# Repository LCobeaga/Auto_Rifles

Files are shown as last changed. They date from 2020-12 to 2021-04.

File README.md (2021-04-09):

Auto Rifles
=====

pretty shot

###### This is a Re-draw of Shadow Price with significant structural and aesthetic improvements that I made over the summer of 2020. It is now to-scale compared to in Destiny and much easier to edit. I plan to make all the other variants of stocks, barrels, and frames seen in the game. Internally, it is still BLDC flywheels and solenoid pusher, but now uses a 16 bit display ammo counter, and includes select fire. It also uses hardware to hold the blaster toghether, unlike the original which was mostly glued together. As a result, most visual components are separate parts, so even without paint the blaster should look very nice, and allows for color swaps if multiple aesthetic components are printed. 

### HARDWARE
#### MECHANICAL
- Six 5mm x 400mm carbon fiber rods
- Five M3 x 8mm heatset inserts
- Three M2 x 4mm heatset inserts
- Five 10mm Nerf style screw
- Four M3 x 12 screws (I used hex socket)
- One M3 x 8 screw
- Four pen springs (one for trigger, two for mag release, and one for priming rod play feature)
- About 1 inch (30mm) of half inch or 14mm PVC pipe (to straighten dart as it leaves the flywheels)
- Electrical or Painters tape (to center and hold pipe at base of barrel)
- ~Four 1kg spools of filament (more if using multiple colors)
#### ELECTRICAL
- One 35mm solenoid (designed for FTW hyperdrive solenoid so a regular one might not fit) https://flywheeltheworld.com/shop/ftw-hyperdrive-solenoid/
- Two 2300KV brushless motors (currently supports 2204 and 1806)
- Two ESCs matching motor amperage draw
- One XT-60 (or preffered) male battery connector
- Two 6mm surface mount (or breadboard compatible) pushbutton switch
- Two D2F-01L3 momentary limit switches (I used the rounded lever)
- One MOSFET or pre-built mosfet board 
- One 10kΩ resistor (only if using raw MOSFET)
- One IN5408 diode (only if using raw MOSFET)
- One 10kΩ potentiometer
- One 32 x 128 I2C OLED display (https://www.dfrobot.com/product-2019.html this is the only one that I know works, but any with the same shape would work too)
- One Arduino Pro Mini 
- High Amperage wires for battery to MOSFET and ESCs
- Small wires for Arduino Connections
- OPTIONAL: JST or other connector type for removeable connections (good for troubleshooting)
- OPTIONAL: Solderable breadboard/raw PCB for wire management

### WIRING DIAGRAM

Auto Rifle

### ASSEMBLY 

1. Glue together the two handle halves (use the lower and knuckle guard bottom to align)



2. Glue handle into the lower



3. Glue details into lower





4. Glue lower covers to lower (make sure to have them align with the cut out for the solenoid



5. Glue lower filler into lower (make sure it is pushed all the way in)


6. Glue together the two knuckle guard pieces



7. Slot mag tooth with spring into lower, slot mag release into the handle, and place the lever into the lower from below



8. Snap the handle cover into place by rotating it in about the trigger guard



9. Slot top of knuckle guard into lower, around the lever and mag release, then slot the tab into the recepticle in the handle and use a nerf screw to lock it in





10. Press magwell covers into slots on either side (DO NOT GLUE, will need to remove later to access wires)



11. Slot in prime pin and prime, place spring behind prime so it will bounce back forward after getting pulled back (can also add some lubricant to smooth movement)



12. Glue detail parts into upper



13. Glue top picatiny into ammo counter (make sure bottom surface flush, the assembly slots into the upper)



14. Glue details into archway



15. Glue archway, top cover, and tail together (assembly called the frame)



16. Cut a 400mm carbon fiber rod in half, and glue into top and bottom of stock filler. Align by first putting rods into upper and lower, then pushing stock filler into them. (all other parts can be optionally glued in, but I suggest against it)



The blue spirals are the M3 heat set inserts, can be added now or later, it does not matter

17. Glue the battery tray strap into the battery tray



#### NO MORE GLUING FROM THIS POINT ON

18. Slot details into stock, and slide stock into dovetails. Place buttstock on back of stock filler. Screw one side of the stock panels into the standoff, then run standoff through the stock filler and screw on other side (they get centered by the upper so dont worry about lateral spacing)



19. Prepare locking lug by inserting the two M3 heat set inserts into the holes



12. At this point you can begin wiring up the blaster, all electronics are housed in the upper other than the trigger switch. Below are photos of switch placement. Wire all switches as normally open, and the mag sensor switch will need the tabs cut down a little if they are too long (the mag sensor can also be flipped upside down if it registers more consistently)





Parts removed for visual clarity



Place a switch on both sides



Make sure not to glue in the OLED or it will make accessing the potentiometer harder



Route ESC and battery cables through this slot (it is ok for them to spill over into the open space, it is well above the magazine and gets covered up)

Add the final M3 Heat set insert into the hole marked by a red spiral

21. Once all the wiring is done, Screw together the flywheel cage assembly, and add in the three M2 heat set inserts to the cage (be careful to not melt through the top of the cage or it will interfere with the flywheels)



22. Slot trigger and trigger axle into the hole in the trigger well, and add the final pen spring in the hole behind it (rotate them in then push up until it snaps in place)



23. Slot stock assembly into back of upper and lower, and screw in the top and bottom



24. Place the barrel filler over the lower filler and slot in another carbon fiber rod (DO NOT GLUE) making sure the rod is flush against the inside of the lower and the front of the barrel (you will have to cut the rod). Also dont forget to place the lock in the front slot of the barrel filler and the barrel rail in the slot on top



25. Place the center filler over the flywheel cage and lock it by slotting the locking lug from behind and another carbon fiber rod from the front. This rod should stick out a little at the front because it sticks into the barrel faceplate, so make sure to check its length and have it flush against the inner wall of the upper. Also screw it down with the longer M3 screws



26. Wrap tape around the small length of PVC and push it down the barrel so it is flush with the front of the flywheel cage

barrel insert

27. Once all the electronics are inside, snap the ammo counter cover into the upper by squeezing the sides, placing it into the cavity, teetering it back and snapping the sides out (make sure they snap past these tabs)


28. Slot ammo counter and picatiny assembly over the electronics and OLED (red arrow), then rotate the oled into the slot on the ammo counter and use the shorter M3 screw to lock it down (blue arrow)



29. Snap the frame over the upper, it will lock in at the front, back, and slot over the cut out in the ammo counter



30. Snap in the top cowl and add the last Nerf screw to hold it down



31. Slot on the barrel clip, it will snap in place once in position



32. Stack up the three parts of the side panels and push a carbon fiber rod almost all the way through them, but dont go through the rectangular opening at the end



33. Push the panel assembly through the barrel clip from the back, and once far enough the opening in the panel will lock over the arc pop-out in the upper and lower



34. Slot on the barrel. It will mesh with the top and both panel carbon fiber rods, and sit flush against the barrel filler front surface and lower rod, so they all need to be at the correct length for this step (tip: if you have problems aligning the rods, push them into the barrel FIRST so you just press the assembly into position, slotting all the rods at the same time)



barrel tips

35. Screw on the muzzle, snap in the battery tray and lock it with the second barrel and you are done!



## CODE

You will need four external libraries to run the code for this blaster. 

They are:
- JC button library https://github.com/JChristensen/JC_Button
  - built in pullup resistor commands, inversion, and debouncing
- Adafruit GFX and SSD1306 (downloadable thru arduino library manager)
  - controls OLED display with easy to understand commands
- Ammo counter (self written library, available in the code directory)
  - ammo counter code written by Monty Choy converted to a library
  
Current issues to work out:
- more descriptive interface with user

## CUSTOM PANELS

If you would like custom panels like the ones on my personal blaster (seen at the top of the read me) a step file is available in the STEP directory. 

The provided STEP includes the two panels as single, large parts and a new barrel clip that does not extend into the central cutout. 
As long as you dont fill in the hole for the rod, the slot in the back, or the cutouts that mesh with the barrel in the front, you can add anything you want to the panels. 
If your printer is not large enough for a full panel (like mine) you can make a design along where you plan to cut the panel, like the eagle head on my personal blaster.
Have fun with it and personalize your blaster to your tastes!

## Fusion File Downloads

They are massive, like 60MB, so if you want them just shoot me an email.

<br />This work is licensed under a <a rel="license" href="http://creativecommons.org/licenses/by-nc-sa/3.0/">Creative Commons Attribution-NonCommercial-ShareAlike 3.0 Unported License</a>.

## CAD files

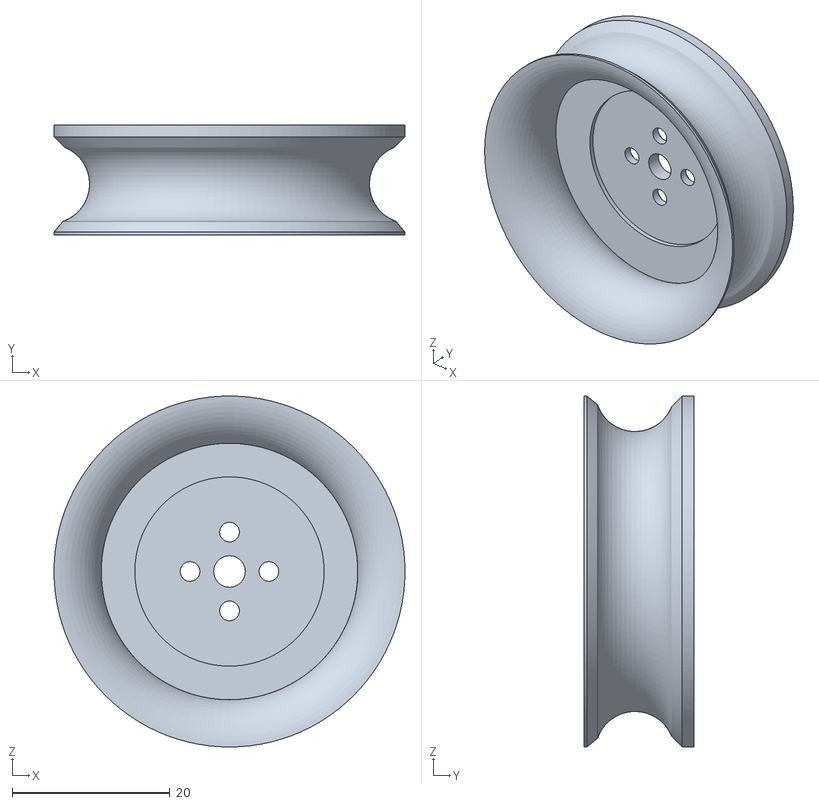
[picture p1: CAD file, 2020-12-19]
parts/cages and wheels/flywheel 2205.stl
44.5 x 14.0 x 44.5

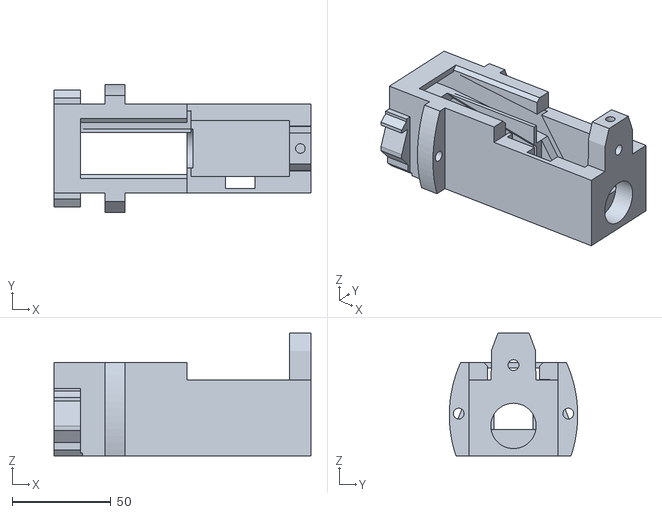
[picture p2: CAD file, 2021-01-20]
parts/Parts_for_smaller_printers/front upper.stl
130.2 x 65.1 x 62.2

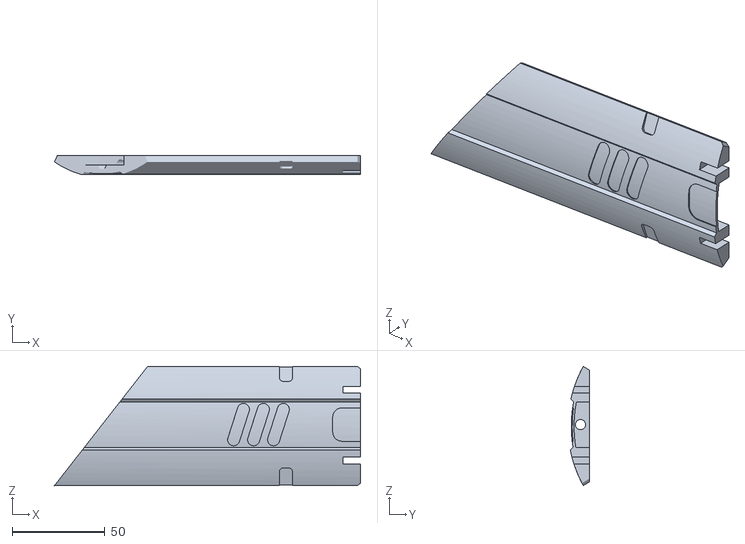
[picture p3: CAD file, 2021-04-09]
parts/Shadow_Price_panels/Front right.stl
165.0 x 10.4 x 64.2

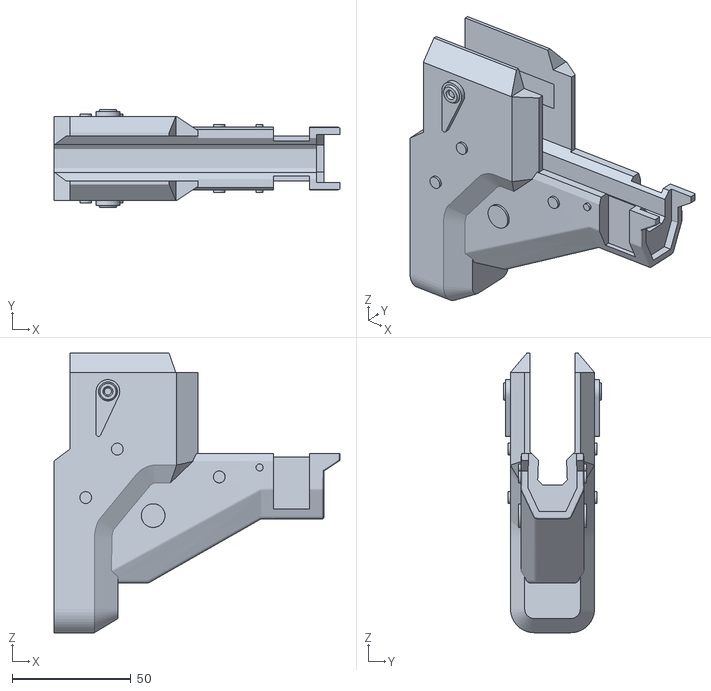
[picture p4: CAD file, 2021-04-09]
parts/stock.stl
120.6 x 41.5 x 117.9

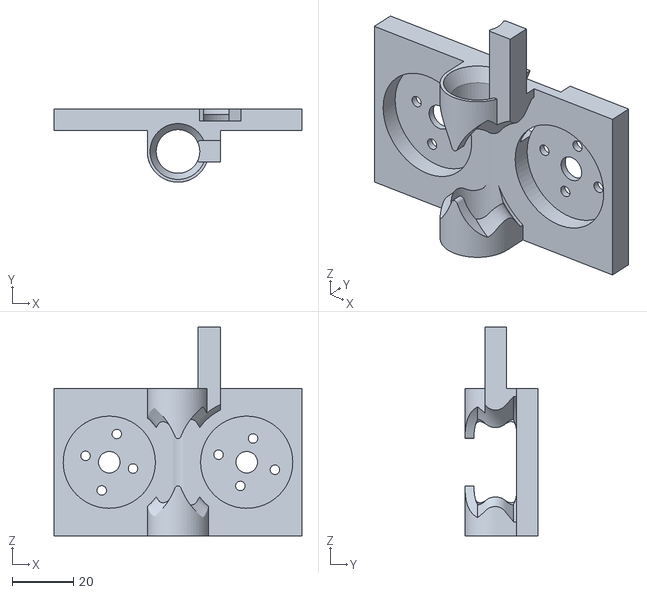
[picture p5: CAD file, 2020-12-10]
parts/cages and wheels/flywheel cage 2205.stl
80.7 x 23.9 x 68.0

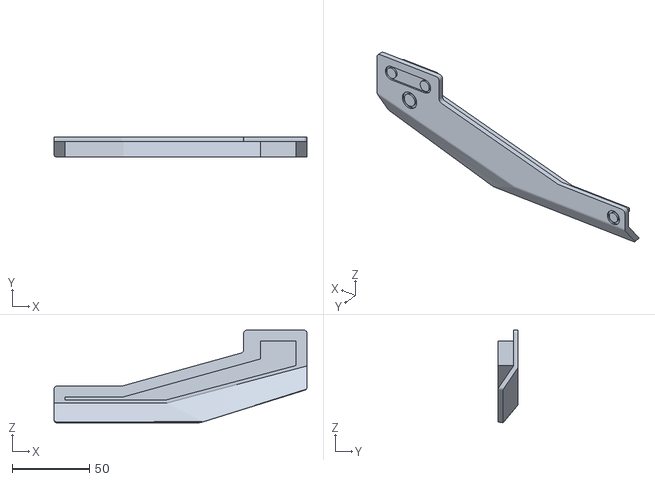
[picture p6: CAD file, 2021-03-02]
parts/left magwell cover.stl
163.8 x 13.1 x 60.0

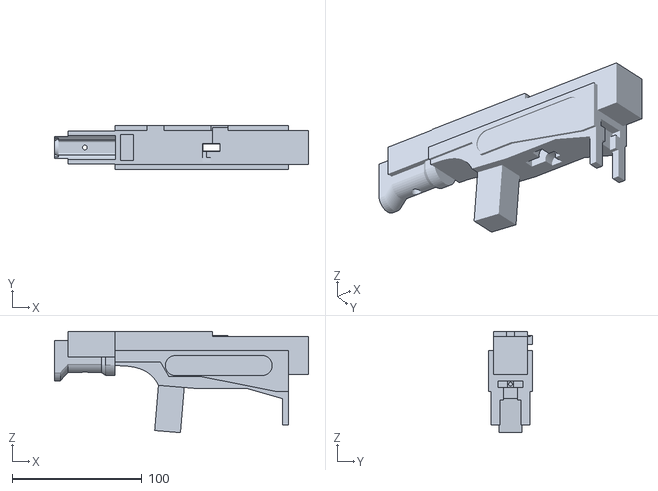
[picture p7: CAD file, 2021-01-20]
parts/Parts_for_smaller_printers/back lower.stl
196.0 x 34.0 x 78.2

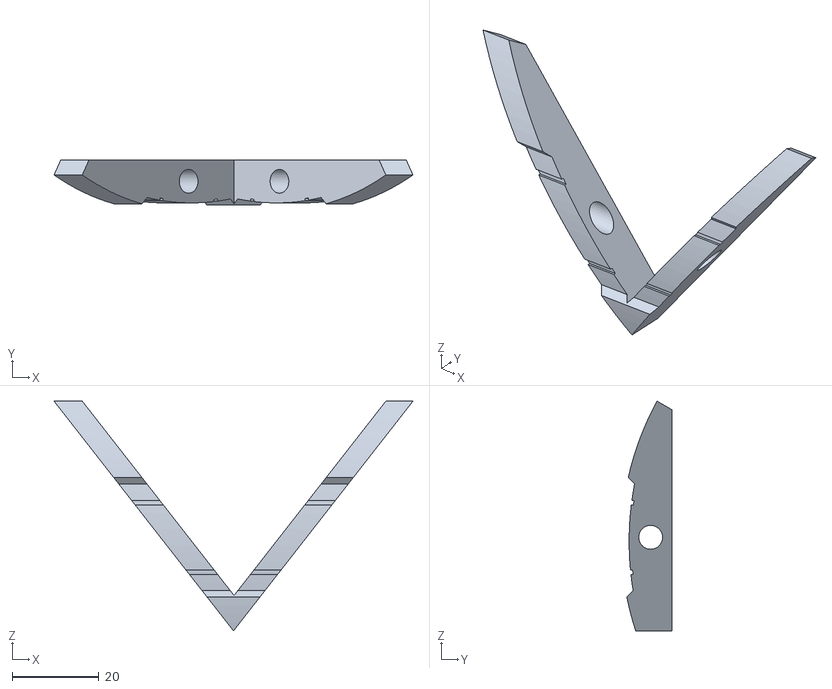
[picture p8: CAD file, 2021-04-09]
parts/Shadow_Price_panels/V gap right.stl
82.7 x 10.4 x 52.9

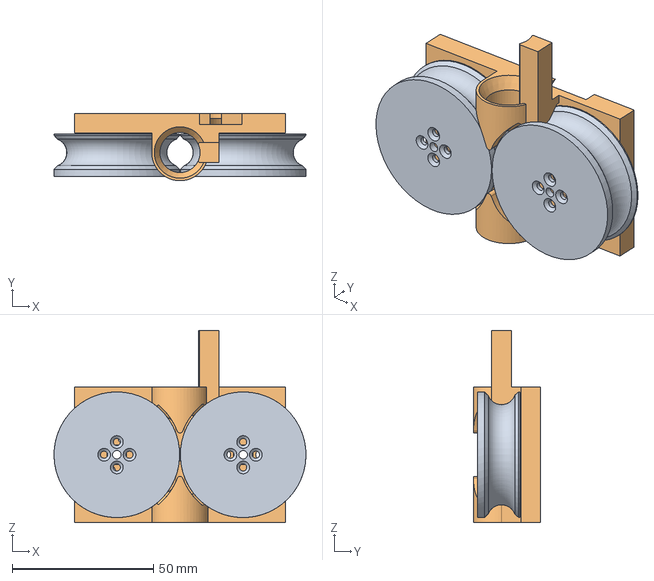
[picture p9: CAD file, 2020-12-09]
parts/cages and wheels/BLDC high crush cage flat 1806 .step
89.2 x 23.9 x 68.0 mm
flywheel_lathed_hi_crush 1806 x 2

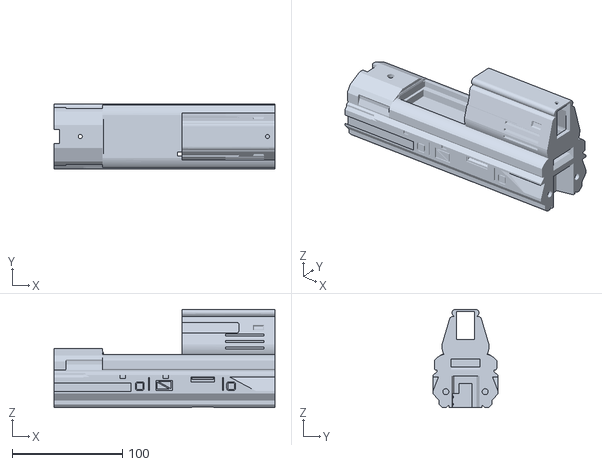
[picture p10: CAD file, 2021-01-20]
parts/Parts_for_smaller_printers/back upper.stl
200.9 x 59.1 x 89.4

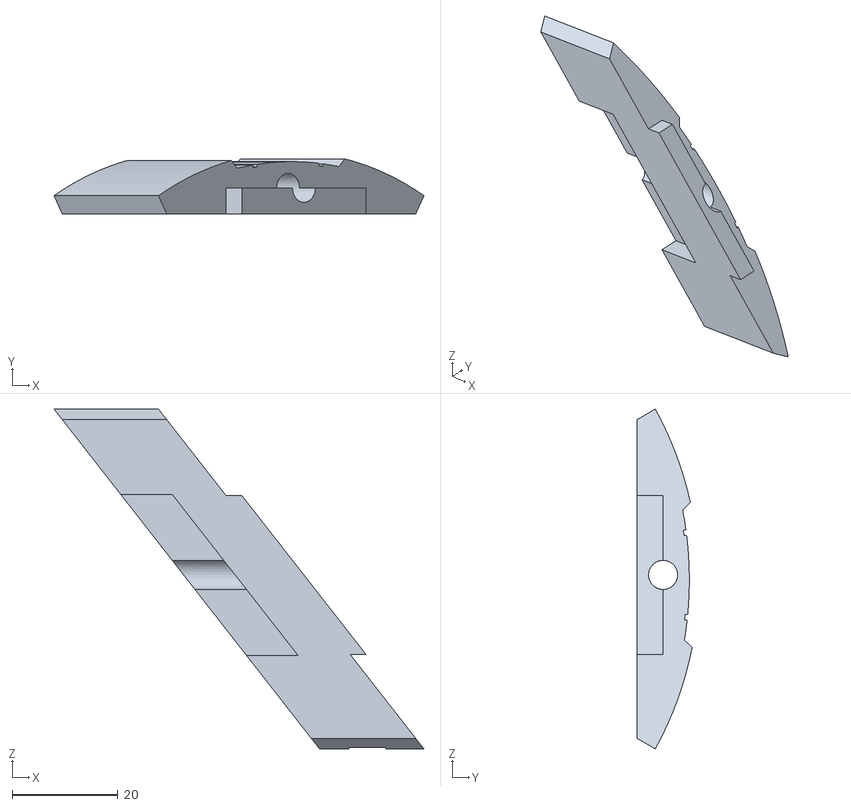
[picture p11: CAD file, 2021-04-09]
parts/Shadow_Price_panels/Stripe left.stl
69.9 x 10.4 x 64.2

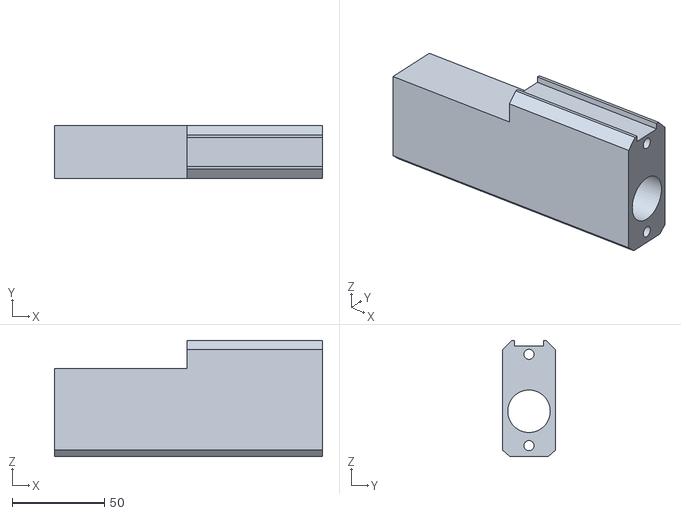
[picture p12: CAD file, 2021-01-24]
parts/back barrel support.stl
145.0 x 28.6 x 63.0

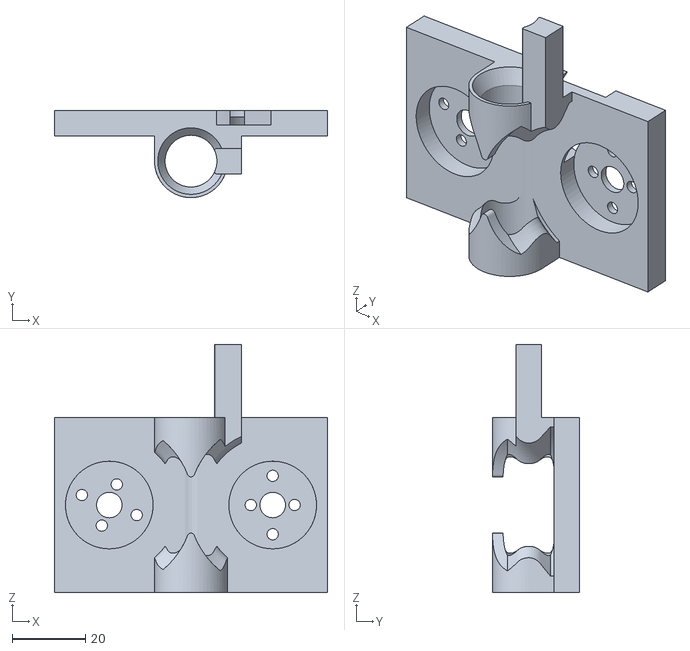
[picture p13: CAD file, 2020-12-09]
parts/cages and wheels/flywheel cage 1806 left.stl
74.7 x 23.9 x 68.0

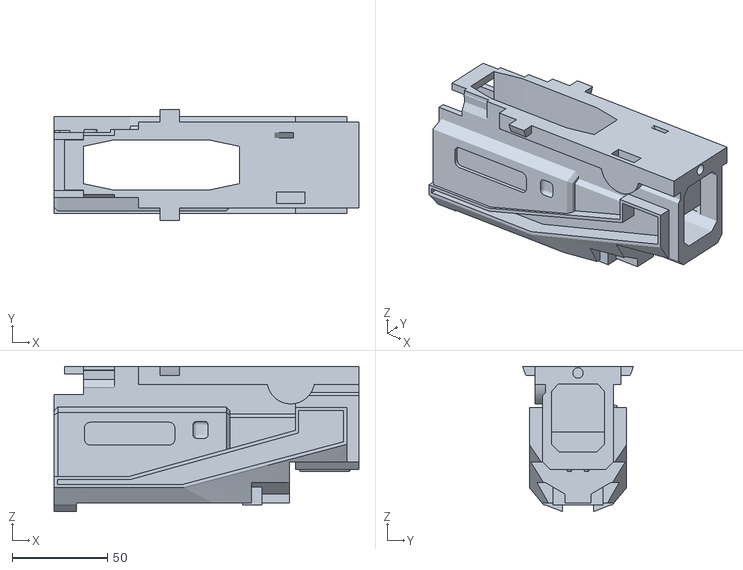
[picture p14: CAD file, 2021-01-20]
parts/Parts_for_smaller_printers/front lower.stl
160.2 x 58.3 x 76.3

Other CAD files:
parts/right magwell cover.stl
parts/Shadow_Price_panels/V gap left.stl
parts/cages and wheels/flywheel smooth 1806.stl
parts/front barrel support.stl
parts/2x lower detail.stl
parts/2x upper detail.stl
parts/Shadow_Price_panels/Back left.stl
parts/Shadow_Price_panels/Back right.stl
parts/Shadow_Price_panels/Front left.stl
parts/Shadow_Price_panels/Stripe Gap left.stl
parts/Shadow_Price_panels/Stripe Gap right.stl
parts/Shadow_Price_panels/Stripe right.stl
parts/Shadow_Price_panels/Triangle left.stl
parts/Shadow_Price_panels/Triangle right.stl
parts/Shadow_Price_panels/V left.stl
parts/Shadow_Price_panels/V right.stl
parts/ammo counter cover.stl
parts/ammo counter.stl
parts/archway.stl
parts/back left greeble.stl
parts/back locking lug.stl
parts/back middle greeble.stl
parts/back right greeble.stl
parts/barrel clip.stl
parts/barrel low.stl
parts/barrel rail.stl
parts/barrel support.stl
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

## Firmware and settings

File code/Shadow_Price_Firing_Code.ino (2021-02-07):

// Shadow Price Firing & ammo counter code
// Written by Luca Cobeaga, go to https://github.com/LCobeaga/Auto_Rifles for updates
// Contact me at lucaslegos@gmail.com

#include <Servo.h>            //brushless motor control library
#include <Adafruit_GFX.h>     //oled display library
#include <Adafruit_SSD1306.h> //monocrome I2C library (pairs with above library)
#include <JC_Button.h>        //button control library
#include <AmmoCounter.h>      //Monty's oled ammocounter code conerted to a library

//pins for button
#define SOLENOID_PIN 6        //solenoid pin
#define RELOAD_BTN_PIN 3      //magazine sensor
#define TRIGGER_BTN_PIN 2     //trigger pin
#define FIRE_MODE_PIN 5       //firing mode toggle 
#define MAG_SZ_TOG_BTN_PIN 4  //mag size toggle
#define MOTOR_PIN 10           //brushless motor pin
#define POT_PIN A3            //potentiometer pin

#define TEXT_SIZE 6  // multiplier on text size
#define ROTATION 1   // rotation of text i.e. 0 = 0deg, 1 = 90deg, 2 = 180deg, 3 = 270deg
#define WIDTH 0      // how far to move from long edge (128 pixel edge)
#define HEIGHT -32   // fow far from edge with wires (32 pixel edge)
#define DEBOUNCE 20  // button debounce time in ms
#define MAXPWM 2000  // motor max PWM 
#define MINPWM 1050  // motor min PWM
#define STOPPWM 1000 // motor stopped PWM
#define INERTIA 4    // time from zero signal to actual motor stop (3 decimal fidelity)

uint32_t ms_last = 0;       // pusher timing
uint32_t cooldown_time = 0; // zero signal motor spindown timing
unsigned int pwm;           // PWM signal for motors
int currSpeed = STOPPWM;    // saved variable for current speed
int mosfetState = HIGH;     // state memory of solenoid
bool fire = false;          // shooting command
byte modeArr[] = {0,1,2,3}; // array of fire modes (0 is full auto, rest are # of darts per trigger pull
byte currentModeInd = 0;    // index of selected mode (starts counting from 0)
byte currentMode = modeArr[currentModeInd]; // actual value of selected mode

/////////////////////////////////////////////////////
// please note that my version of the ammo counter //
// has them written vertically, so my height and   //
// width are reversed compared to the screen orign //
/////////////////////////////////////////////////////

Servo flywheel;                                                                              //create servo object to control the esc 
Button selectFire(FIRE_MODE_PIN, DEBOUNCE, true, true);                                      //create button for select fire
Button trigger(TRIGGER_BTN_PIN, 30, true, true);                                             //create button for trigger
AmmoCounter AC = AmmoCounter(TRIGGER_BTN_PIN, RELOAD_BTN_PIN, MAG_SZ_TOG_BTN_PIN, DEBOUNCE); //create ammo counter object

void setup() {
  AC.begin(TEXT_SIZE, ROTATION, WIDTH, HEIGHT); // ammo counter start
  selectFire.begin();                           // select fire button start
  trigger.begin();                              // trigger button start
  flywheel.attach(MOTOR_PIN);                   // brushless motor attach
  pinMode(SOLENOID_PIN,OUTPUT);                 // solenoid attach

////////////////////////////////////////////
// DO NOT USE WITH BLHELI ESCS. THIS CODE //
// WILL BURN OUT YOUR MOTORS. FOR SIMONK  //
// ONLY                                   //
////////////////////////////////////////////
  //Serial.begin(9600);
  
}

void loop() {
  int potVal = analogRead(POT_PIN); // checks to see current 
  trigger.read();                   // checks if button pressed
  if(trigger.wasPressed()) {            // self explanatory
    pwm = map(potVal,0,1023,1300,1800); // maps potentiometer to the PWM value to send to the motors
    fire = true;                        // input to pusher 
    rev(pwm,currSpeed,cooldown_time);                 // input to flywheels
    currSpeed = pwm;                    // saving pwm for use in decelerating
    
    if(currentMode == 0){               // check for full auto
      while(trigger.isPressed()){       // self explanatory
        pusher(fire);                   // pusher function
        AC.countAmmo(fire);             // count ammo, must be fed boolean 
        trigger.read();                 // check trigger again so not to get stuck in while loop
      }
    }
    
    else {                                      // for all other fire modes
      for(int i = 0; i<= (currentMode-1); i++){ // loop for the amount of shots in the burst
      pusher(fire);                             // pusher function
      AC.countAmmo(fire);                       //count ammo, must be fed boolean 
      }
    }
  }
  else {
    if(currSpeed>STOPPWM) cooldown_time = millis();
    fire = false;                         // input to pusher
    currSpeed = decel(pwm, currSpeed, cooldown_time);    // controlled decelleration of motors based on target speed
    pusher(fire);                         // keeps pusher off
  }

  currentMode = mode(); // function to check if mode swapped
  AC.reload();          //reload, constantly check for the magazine switch to be pressed/not pressed
  AC.toggleMags();      //toggle between magazine sizes, constanly check for the magazine toggle switch to be pressed
}

void pusher (bool fire) {
  int change = 0;             // for loop exit variable

  while(change<2){            // loop to keep pusher timing
    uint32_t ms = millis();   // timing variable
    if (ms - ms_last >= 85) { // timing setup
      
      ms_last = ms;           // timing exit variable

      // state swapper for pusher
      if (mosfetState == LOW) mosfetState = HIGH; 
      else mosfetState = LOW;

      // saftey check to make sure pusher never gets stuck in out position
      if (!fire) {
        mosfetState = LOW; 
      }
      change ++;                                // indexing loop variable 
      digitalWrite(SOLENOID_PIN, mosfetState);  // actually moving the pusher
    }
  }
}

byte mode() {
  selectFire.read();  // check if select fire button was pressed
  if(selectFire.wasPressed()){
    currentModeInd = (currentModeInd < (sizeof(modeArr)/sizeof(modeArr[0]) - 1)) ? currentModeInd + 1 : 0; // indexing thru array with roll over protection

    currentMode = modeArr[currentModeInd]; // grabs burst value from array
    String dispMode = (String)currentMode; // prepares to display burst amount
    AC.displayAmmo(dispMode);              // displays burst amount
  }
  return currentMode; // pushes burst value out of function
}

void rev(int pwm, int Speed, uint32_t cooldown_time){
  uint32_t ms = millis();
  if (Speed <= STOPPWM && (ms - cooldown_time) > INERTIA*1000){ // if flywheels are not spinning 
    int Speed = MAXPWM; // variable pwm value for ramping speed

    // adaptive delay
    int rampSize = 1; //map(pwm,MINPWM,MAXPWM,10,0);   // using two variables here for optimised speed up 
    int wait = map(pwm,MINPWM,MAXPWM,150,2000); // i.e. just changing the indexing is too small a range to work with, using both gives more control
    while (Speed > pwm){

      flywheel.writeMicroseconds(Speed); 
      //Serial.println("ramp1");
      Speed -= rampSize;
      delayMicroseconds(wait);
    }

    flywheel.writeMicroseconds(pwm); // final speed to hold during firing
    
  }
  
  else { // if flywheels still moving 
    int rampSize = map(pwm,MINPWM,MAXPWM,1,10);
    int offSpeedDelay = map(pwm,MINPWM,MAXPWM,380,80);

    int saveSpeed = Speed;
    // if below desired speed ramp up
    while (Speed < pwm){ 
      flywheel.writeMicroseconds(currSpeed); 
      //Serial.println("ramp2");
      Speed += rampSize;
      delayMicroseconds(100);
    }
    // if above desired speed ramp down
    while (Speed > pwm){
      flywheel.writeMicroseconds(currSpeed); 
      //Serial.println("ramp3");
      Speed -= rampSize;
      delayMicroseconds(100);
    }

    flywheel.writeMicroseconds(pwm); // hold speed
    if (saveSpeed <= STOPPWM) delay(offSpeedDelay);
  }
}

int decel(int pwm, int Speed, uint32_t cooldown_time){
  if(Speed>STOPPWM) Speed -= map(pwm,MINPWM,MAXPWM,7,50);  // adaptive ramp down
  else flywheel.writeMicroseconds(STOPPWM);                // check to make sure flywheels stay off
  flywheel.writeMicroseconds(Speed);                       // set speed to ramp down amount
  //Serial.println("ramp4");
  return Speed;                                            // output speed to create a feedback loop for full deceleration, or follow up shots
}

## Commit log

2020-12-02 personal printed version, not optimised
    [2x lower detail.stl, 2x upper detail.stl, ammo counter cover.stl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]
2020-12-02 missing cage, wheels, upper, and lower
    [2x lower detail.stl, 2x upper detail.stl, ammo counter cover.stl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]
2020-12-02 missing and updated parts
    [archway.stl, lower.stl, tail.stl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]
2020-12-09 Custom panel STEP and my panels
    [barrel clip modified.step, barrel clip.stl, left panel back.stl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]
2020-12-09 use to make cage using other motors
    [BLDC high crush cage flat 1806 .step]
2020-12-10 updated 35mm solenoid listing
2020-12-10 diode added to part list and wiring diagram
2020-12-19 fixed height, for original FDL2 style motors
    [flywheel 2205.stl]
2021-01-12 structural improvements
    [battery tray.stl]
2021-01-12 fixed spelling
    [left panel front.stl]
2021-01-20 lower and upper cut in half for smaller print beds
    Only use these if you cant print the full size ones
    [back lower.stl, back upper.stl, front lower.stl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]
2021-01-24 barrel support cut in half for smaller printers
    [back barrel support.stl, front barrel support.stl]
2021-02-01 better rev up speed
    need to add a sequence at the end of the rev down to account for motor inertia
2021-02-07 tertiary rev up sequence for non-braking motors
    Added a timer that will send the code to the "still moving" rev up protocol for a user defined amount of seconds after the motors have received 0 speed signal.
    I.E. I added inertia compensation since moving wheels don't need the acceleration spike, just a small delay
2021-03-02 removed lower edge for ease of printing
    [left magwell cover.stl, right magwell cover.stl]
